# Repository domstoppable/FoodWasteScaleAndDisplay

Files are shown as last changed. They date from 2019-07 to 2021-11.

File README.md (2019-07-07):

# Food waste scale and display

## Firmware
Build and upload with Arduino

## Display app
### Building
* Install [`react-native`](https://facebook.github.io/react-native/docs/getting-started)
* Install the Android SDK
* Make sure the `ANDROID_HOME` environment variable is set appropriately
* Build and test the app
	```bash
	cd ScaleDisplayApp
	npm install
	npm run-android
	```
* Make a native release build and install it ([signing key required](https://facebook.github.io/react-native/docs/signed-apk-android))
	```bash
	cd ScaleDisplayApp/android
	./gradlew assembleRelease
	adb install build/outputs/apk/release/app-release.apk
	cd ..
	```

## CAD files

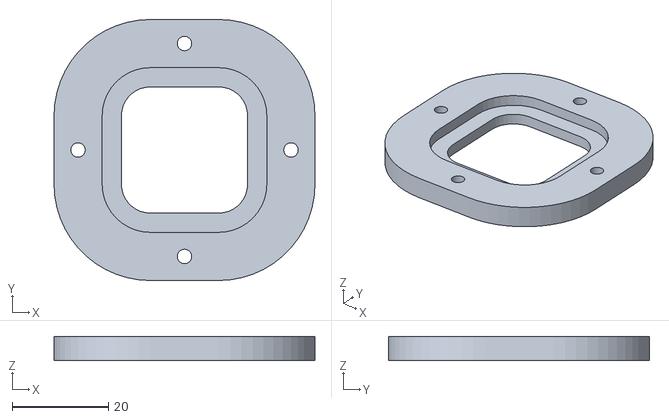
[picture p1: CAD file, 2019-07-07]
3d-models/bracket-plain.stl
54.2 x 54.2 x 5.00

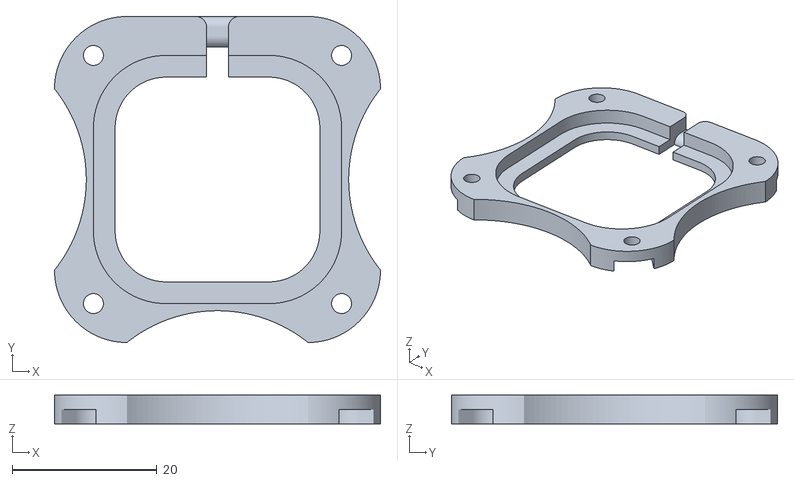
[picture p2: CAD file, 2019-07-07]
3d-models/Load cell bracket.stl
45.0 x 45.0 x 4.00

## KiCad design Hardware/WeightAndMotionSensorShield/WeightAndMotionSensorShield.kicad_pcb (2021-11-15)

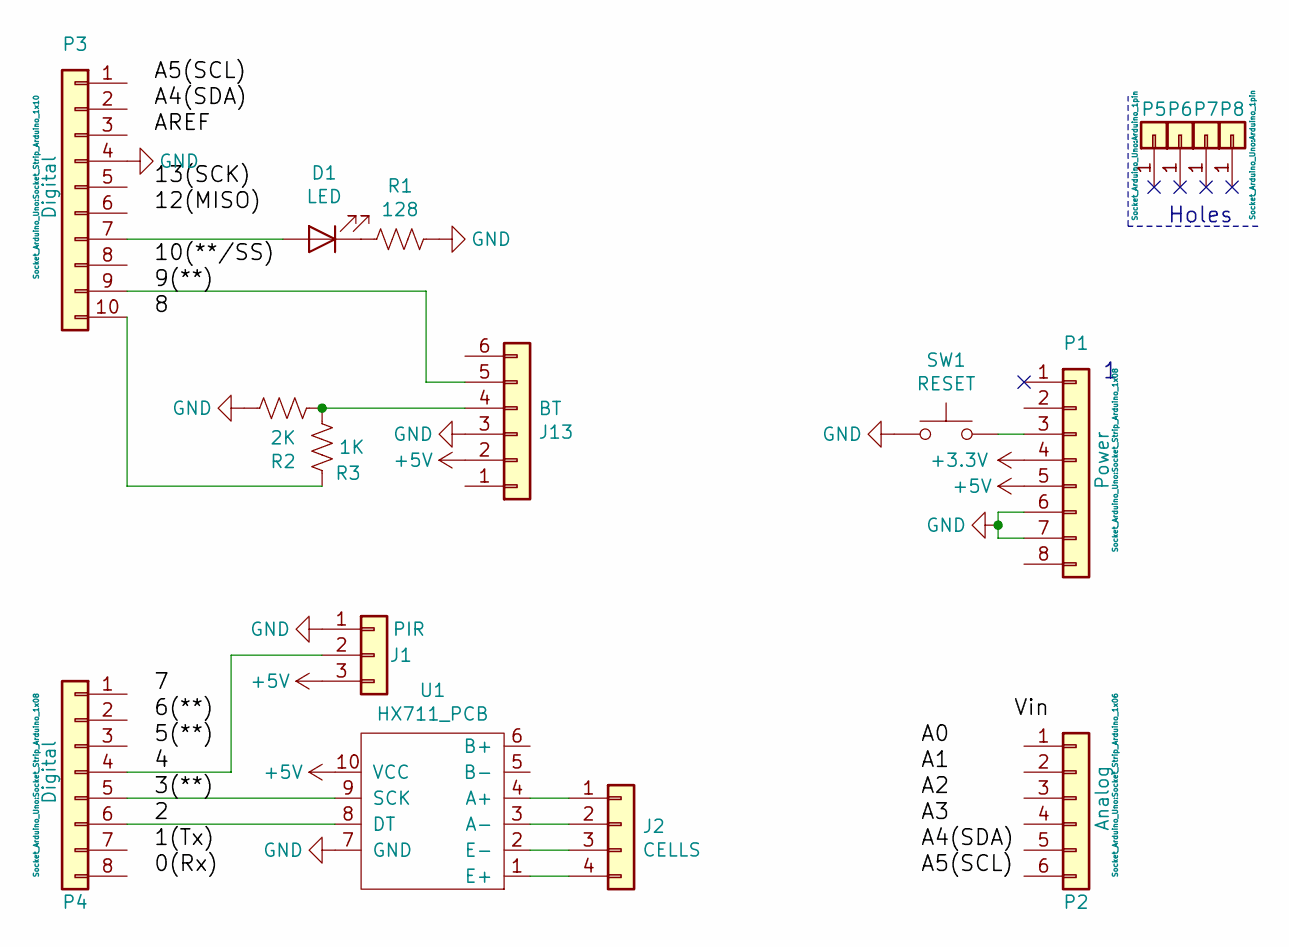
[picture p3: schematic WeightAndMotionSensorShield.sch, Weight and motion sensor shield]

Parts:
D1: LED; LED_D5.0mm
J1: PIR; PinSocket_1x03_P2.54mm_Horizontal
J2: CELLS; PinSocket_1x04_P2.54mm_Horizontal
J13: BT; PinHeader_1x06_P2.54mm_Vertical
P1: Power; Socket_Strip_Arduino_1x08
P2: Analog; Socket_Strip_Arduino_1x06
P3: Digital; Socket_Strip_Arduino_1x10
P4: Digital; Socket_Strip_Arduino_1x08
P5, P6, P7, P8: CONN_01X01; Arduino_1pin
R1: 128; R_Axial_DIN0207_L6.3mm_D2.5mm_P10.16mm_Horizontal
R2: 2K; R_Axial_DIN0207_L6.3mm_D2.5mm_P10.16mm_Horizontal
R3: 1K; R_Axial_DIN0207_L6.3mm_D2.5mm_P10.16mm_Horizontal
SW1: RESET; SW_PUSH_6mm
U1: HX711_PCB

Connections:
+3V3: P1.4
+5V: J1.3, J13.2, P1.5, U1.10 (VCC); also elsewhere on the board
/2: P4.6, U1.8 (DT)
/3(**): P4.5, U1.9 (SCK)
/4: J1.2, P4.4; also elsewhere on the board
/9(**): J13.5, P3.9
GND: J1.1, J13.3, P1.6, P1.7, P3.4, R1.1, R2.1, SW1.1, U1.7 (GND); also elsewhere on the board
unnamed: D1.1 (K), R1.2
unnamed: D1.2 (A), P3.7
unnamed: J2.1, U1.4 (A+)
unnamed: J2.2, U1.3 (A-)
unnamed: J2.3, U1.2 (E-)
unnamed: J2.4, U1.1 (E+)
unnamed: J13.4, R2.2, R3.2
unnamed: P1.3, SW1.2
unnamed: P3.10, R3.1

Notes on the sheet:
Holes

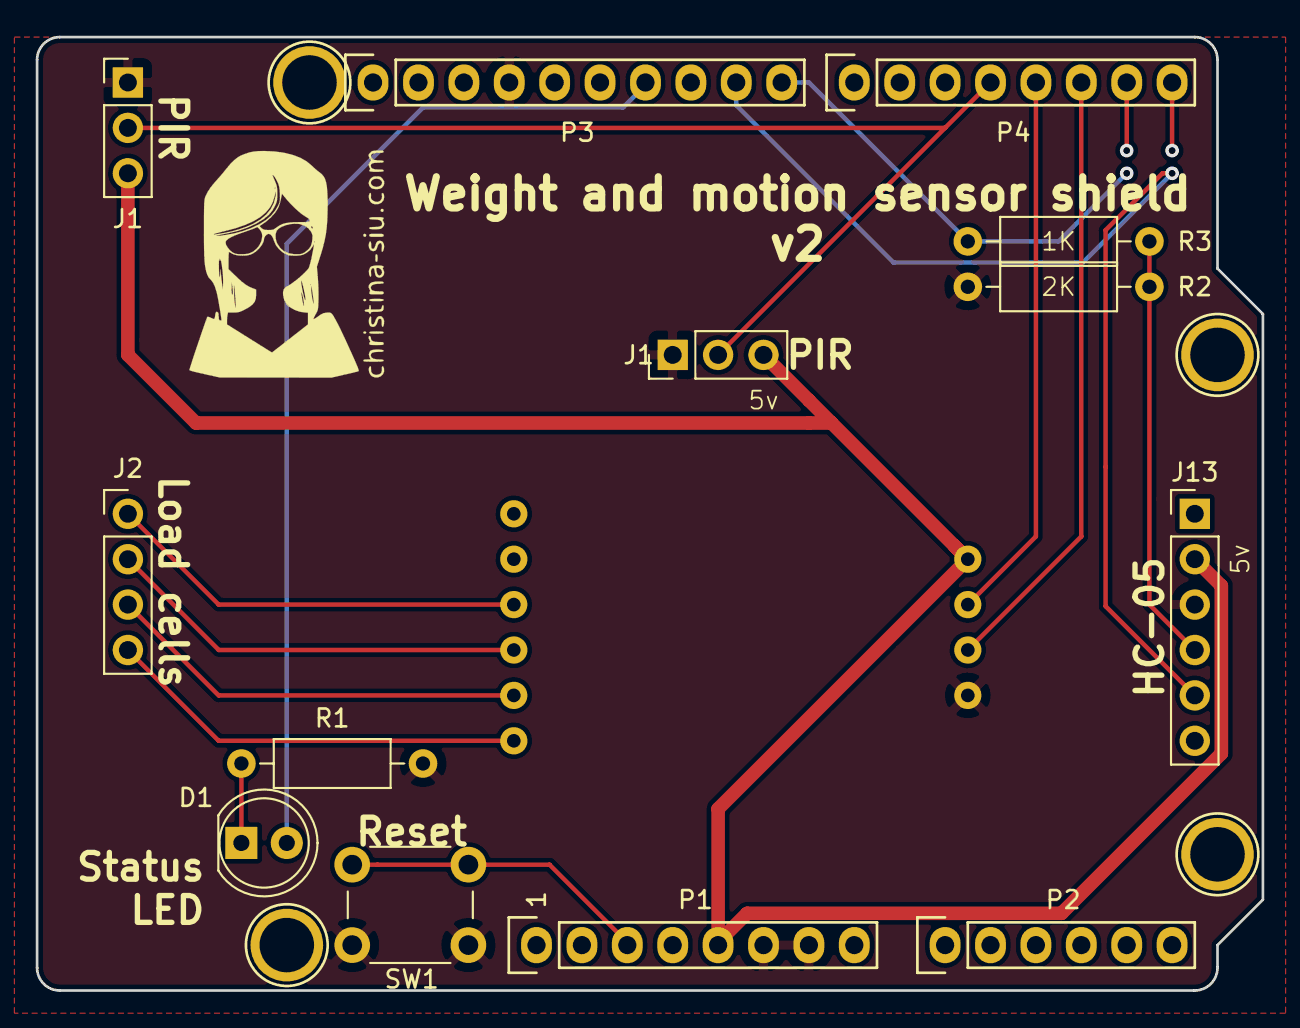
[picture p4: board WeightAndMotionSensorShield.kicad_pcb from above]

Board: 2 copper layers, 68.6 x 53.3 mm, 18 parts (1 on the bottom side), 15 nets.

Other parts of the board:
J1#2: PIR; PinHeader_1x03_P2.54mm_Vertical

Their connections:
+5V: J1#2.3; also elsewhere on the board
/4: J1#2.2; also elsewhere on the board
GND: J1#2.1; also elsewhere on the board

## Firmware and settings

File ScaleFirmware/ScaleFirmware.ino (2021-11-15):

#include <SoftwareSerial.h>
#include "HX711_ADC.h"
#include "PIRSensor.h"

HX711_ADC loadCell(2, 3); // DT, SCK
long lastLoadCellUpdate = 0l;

PIRSensor motionSensor(4);

int ledPin = 11;
long ledOnTime = 0l;
float curWeight = 0;
float calibrationFactor = -5096;
String inputString = "";
SoftwareSerial bluetoothSerial(8, 9); // RX, TX

void setup() {
	Serial.begin(9600);
	Serial.println("Initializing...");
  
	pinMode(ledPin, OUTPUT);

	digitalWrite(ledPin, HIGH);
  	delay(100);
	digitalWrite(ledPin, LOW);

	bluetoothSerial.begin(9600);

	loadCell.begin();
	loadCell.start(2000);
	loadCell.setCalFactor(696.0); // user set calibration factor (float)

	motionSensor.begin();

	for(int i=0; i<3; i++){
		digitalWrite(ledPin, HIGH);
		delay(100);
		digitalWrite(ledPin, LOW);
		delay(100);
	}

	Serial.println("Setup complete! Starting loop...");
}

void loop(){
	long currentTime = millis();

	//if(motionSensor.update()){
	//	if(motionSensor.state && ledOnTime == 0l){
//			bluetoothSerial.println("m");
//      Serial.print("m");
//			Serial.println("Motion detected!");
		///}
		//digitalWrite(ledPin, HIGH);
		//ledOnTime = currentTime;
	//}
	loadCell.update();

	if (currentTime > lastLoadCellUpdate + 500) {
		curWeight = loadCell.getData()*453.592;
    float i =  int(curWeight); //grams //float(int(curWeight/10))/100; //kg
		float v = loadCell.getCalFactor();

		bluetoothSerial.print("w");
		bluetoothSerial.println(i);
   Serial.print("Calibration Factor: ");
   Serial.print(calibrationFactor);
   Serial.print("Sending weight: ");
   Serial.println(i);
//		Serial.print("Sending weight: ");
//		Serial.println(i);

		lastLoadCellUpdate = currentTime;
	}
        
//	if(ledOnTime > 0l && currentTime > ledOnTime + 1000){
//		ledOnTime = 0l;
//		Serial.println("Disabling LED");
//		digitalWrite(ledPin, LOW);
//	}
 if(bluetoothSerial.available()>0)
  {
//    bluetoothSerial.println("P");
    char temp = bluetoothSerial.read();
    Serial.println(temp);
    if(temp == 't'){
      loadCell.tare(); //Reset the scale to 0
      bluetoothSerial.println("R");
    }
    else if(temp == 'a'){
      calibrationFactor += 500;
      loadCell.setCalFactor(calibrationFactor);
      bluetoothSerial.println("A");
    }
    else if(temp == 'z'){
      calibrationFactor -= 500;
      loadCell.setCalFactor(calibrationFactor);
      bluetoothSerial.println("Z");
    }
    else if(temp == 's'){
      calibrationFactor += 50;
      loadCell.setCalFactor(calibrationFactor);
      bluetoothSerial.println("A");
    }
    else if(temp == 'x'){
      calibrationFactor -= 50;
      loadCell.setCalFactor(calibrationFactor);
      bluetoothSerial.println("Z");
    }
    else if(temp=='g'){
      bluetoothSerial.print('g');
      bluetoothSerial.println(calibrationFactor);
      
    }
    else if(temp=='h'){
      delay(1000);
      float temp2 = bluetoothSerial.parseInt();
      
//      while(bluetoothSerial.available()>0){
//        delay(100);
//        char inChar = bluetoothSerial.read();
//        Serial.println(inChar);
//        inputString += inChar; 
//      }
////      float temp3 = bluetoothSerial.parseInt();
//      Serial.println(inputString);
//      inputString = "";
      calibrationFactor = float(temp2);
//      bluetoothSerial.println(temp2);
      Serial.println(calibrationFactor);
      loadCell.setCalFactor(calibrationFactor);
    }
      
      
      
  }
}

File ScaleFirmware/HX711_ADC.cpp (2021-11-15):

//-------------------------------------------------------------------------------------
// HX711_ADC.h
// Arduino master library for HX711 24-Bit Analog-to-Digital Converter for Weigh Scales
// Olav Kallhovd sept2017
// Tested with      : HX711 asian module on channel A and YZC-133 3kg load cell
// Tested with MCU	: Arduino Nano
//-------------------------------------------------------------------------------------

#include <Arduino.h>
#include "HX711_ADC.h"


HX711_ADC::HX711_ADC(uint8_t dout, uint8_t sck) //constructor
{ 	
	doutPin = dout;
	sckPin = sck;
} 

void HX711_ADC::setGain(uint8_t gain)  //value should be 32, 64 or 128*
{
	if(gain < 64) GAIN = 2; //32, channel B
	else if(gain < 128) GAIN = 3; //64, channel A
	else GAIN = 1; //128, channel A
}

void HX711_ADC::begin()
{
	pinMode(sckPin, OUTPUT);
	pinMode(doutPin, INPUT);
	setGain(128);
	powerUp();
}


void HX711_ADC::begin(uint8_t gain)
{
	pinMode(sckPin, OUTPUT);
	pinMode(doutPin, INPUT);
	setGain(gain);
	powerUp();
}

/*  start(t): will do conversions continuously for 't' +400 milliseconds (400ms is min. settling time at 10SPS). 
*   Running this for 1-5s before tare() seems to improve the tare accuracy */
int HX711_ADC::start(unsigned int t)
{
	t += 400;
	while(millis() < t) 
	{
		getData();
		yield();
	}
	tare();
	tareStatus = 0;
}	

/*  startMultiple(t): use this if you have more than one load cell and you want to do tare and stabilization simultaneously.
	Will do conversions continuously for 't' +400 milliseconds (400ms is min. settling time at 10SPS). 
*   Running this for 1-5s before tare() seems to improve the tare accuracy */
int HX711_ADC::startMultiple(unsigned int t)
{
	tareTimeoutFlag = 0;
	static unsigned long timeout = millis() + tareTimeOut;
	if(startStatus == 0) {
		if(isFirst) {
			startMultipleTimeStamp = millis();
			if (t < 400) 
			{
				startMultipleWaitTime = t + 400; //min time for HX711 to be stable
			} 
			else 
			{
				startMultipleWaitTime = t;
			}
			isFirst = 0;
		}	
		if(millis() < startMultipleTimeStamp + startMultipleWaitTime) {
			update(); //do conversions during stabilization time
			yield();
			return 0;
		}
		else { //do tare after stabilization time is up
			doTare = 1;
			update();
			if(convRslt == 2) 
			{	
				doTare = 0;
				convRslt = 0;
				startStatus = 1;
			}
			if (!tareTimeoutDisable) 
			{
				if (millis() > timeout) 
				{ 
				tareTimeoutFlag = 1;
				return 1; // Prevent endless loop if no HX711 is connected
				}
			}
		}
	}
	return startStatus;
}

void HX711_ADC::tare() 
{
	uint8_t rdy = 0;
	doTare = 1;
	tareTimes = 0;
	tareTimeoutFlag = 0;
	unsigned long timeout = millis() + tareTimeOut;
	while(rdy != 2) 
	{
		rdy = update();
		if (!tareTimeoutDisable) 
		{
			if (millis() > timeout) 
			{ 
				tareTimeoutFlag = 1;
				break; // Prevent endless loop if no HX711 is connected
			}
		}
		yield();
	}
}

bool HX711_ADC::getTareStatus() 
{
	bool t = tareStatus;
	tareStatus = 0;
	return t;
}

void HX711_ADC::tareNoDelay() 
{
	doTare = 1;
	tareTimes = 0;
}

void HX711_ADC::setCalFactor(float cal) //raw data is divided by this value to convert to readable data
{
	calFactor = cal;
}

float HX711_ADC::getCalFactor() //raw data is divided by this value to convert to readable data
{
	return calFactor;
}

//call function update() in loop
//if conversion is ready; read out 24 bit data and add to data set, returns 1
//if tare operation is complete, returns 2
//else returns 0
uint8_t HX711_ADC::update() 
{
	byte dout = digitalRead(doutPin); //check if conversion is ready
	if (!dout) 
	{
		conversion24bit();
		//if(s) Serial.print(s);
	}
	else convRslt = 0;
	return convRslt;
}

float HX711_ADC::getData() // return fresh data from the moving average data set
{
	//long k = 0;
	long data = 0;
	//data = smoothedData() - tareOffset;
	lastSmoothedData = smoothedData();
	data = (lastSmoothedData >> divBit) - tareOffset ;
	//data = (data >> divBit);
	
	float x = (float)data / calFactor;
	return x;
}

long HX711_ADC::smoothedData() 
{
	long data = 0;
	long L = 0xFFFFFF;
	long H = 0x00;
	//for (uint8_t r = 0; r < DATA_SET; r++) {
	for (uint8_t r = 0; r < (samplesInUse + IGN_HIGH_SAMPLE + IGN_LOW_SAMPLE); r++) 
	{
		if (L > dataSampleSet[r]) L = dataSampleSet[r]; // find lowest value
		if (H < dataSampleSet[r]) H = dataSampleSet[r]; // find highest value
		data += dataSampleSet[r];
	}
	if(IGN_LOW_SAMPLE) data -= L; //remove lowest value
	if(IGN_HIGH_SAMPLE) data -= H; //remove highest value
	return data;
}

uint8_t HX711_ADC::conversion24bit()  //read 24 bit data and start the next conversion
{
	conversionTime = micros() - conversionStartTime;
	conversionStartTime = micros();
	unsigned long data = 0;
	uint8_t dout;
	convRslt = 0;
	if(SCK_DISABLE_INTERRUPTS) noInterrupts();
	for (uint8_t i = 0; i < (24 + GAIN); i++) 
	{ //read 24 bit data + set gain and start next conversion
		if(SCK_DELAY) delayMicroseconds(1); // could be required for faster mcu's, set value in config.h
		digitalWrite(sckPin, 1);
		if(SCK_DELAY) delayMicroseconds(1); // could be required for faster mcu's, set value in config.h
		if (i < (24)) 
		{
			dout = digitalRead(doutPin);
			data = data << 1;
			if (dout) 
			{
				data++;
			}
		}
		digitalWrite(sckPin, 0);
	}
	if(SCK_DISABLE_INTERRUPTS) interrupts(); 
	data = data ^ 0x800000; // if out of range (min), change to 0
	//if (readIndex == DATA_SET - 1) {
	if (readIndex == samplesInUse + IGN_HIGH_SAMPLE + IGN_LOW_SAMPLE - 1) 
	{
		readIndex = 0;
	}
	else 
	{
		readIndex++;
	}
	if(data > 0)  
	{
		convRslt++;
		dataSampleSet[readIndex] = (long)data;
		if(doTare) 
		{
			if (tareTimes < DATA_SET) 
			{
				tareTimes++;
			}
			else 
			{
				//tareOffset = smoothedData();
				tareOffset = (smoothedData() >> divBit);
				tareTimes = 0;
				doTare = 0;
				tareStatus = 1;
				convRslt++;
			}
		}
	}
}

void HX711_ADC::powerDown() 
{
	digitalWrite(sckPin, LOW);
	digitalWrite(sckPin, HIGH);
}

void HX711_ADC::powerUp() 
{
	digitalWrite(sckPin, LOW);
}

//get the tare offset (raw data value output without the scale "CalFactor")
long HX711_ADC::getTareOffset() 
{
	return tareOffset;
}

//set new tare offset (raw data value input without the scale "CalFactor")
void HX711_ADC::setTareOffset(long newoffset)
{
	tareOffset = newoffset;
}

//for testing and debugging:
//returns current value of readIndex
int HX711_ADC::getReadIndex()
{
	return readIndex;
}

//for testing and debugging:
//returns latest conversion time in millis
float HX711_ADC::getConversionTime()
{
	return conversionTime/1000.0;
}

//for testing and debugging:
//returns the HX711 samples ea seconds based on the latest conversion time. 
//The HX711 can be set to 10SPS or 80SPS. For general use the recommended setting is 10SPS.
float HX711_ADC::getSPS()
{
	float sps = 1000000.0/conversionTime;
	return sps;
}

//for testing and debugging:
//returns the tare timeout flag from the last tare operation. 
//0 = no timeout, 1 = timeout
bool HX711_ADC::getTareTimeoutFlag() 
{
	return tareTimeoutFlag;
}
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

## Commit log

2019-07-16 Add PCB design for Arduino shield
    [WeightAndMotionSensorShield-B.Cu.gbl, WeightAndMotionSensorShield-B.Mask.gbs, WeightAndMotionSensorShield-B.SilkS.gbo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]
2019-07-23 Adds LED, reset button, 2nd PIR header
    [WeightAndMotionSensorShield-B.Cu.gbl, WeightAndMotionSensorShield-B.Mask.gbs, WeightAndMotionSensorShield-B.SilkS.gbo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]
2019-08-18 PCB v1.1 and 2 changes
    [WeightAndMotionSensorShield-B.Cu.gbl, WeightAndMotionSensorShield-B.Mask.gbs, WeightAndMotionSensorShield-B.SilkS.gbo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]
2019-10-10 Added functioning Baseline and Ambient conditions. Need pictures and colors for the Ambient and Metaphorical conditions. Data can be logged locally via RNFetchBlob Operator button located in the bott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
    TODO: Google Sheets and Weight detector (to determine logging)
2020-01-10 More functions
    [config.txt]
2020-01-12 Sort of functioning for BLE devices, but the HC-05 unit ordered is not BLE
2020-01-12 Working bluetooth data reader. Need to do a lot more to stabilize things
    1) Bluetooth picker
    2) Auto-connect
    3) Properly disconnect bluetooth device so you do not need to completely disconnect bluetooth from power
2020-01-13 Added arduino updated script so that we can send command to tare
2020-01-13 Added calibration menu Added ToastAndroid instead of console.warns everywhere for some crisper tastes Need to figure out weightchange algorithm. Can detect changes, but need to think of how to contin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
    [config.txt]
2020-01-20 Add header for HC-05 module
    [WeightAndMotionSensorShield.kicad_pcb, WeightAndMotionSensorShield.sch]
2020-03-07 Fixed calibrations to save values from configCal file
2020-03-14 Update pins for new board + add LED pin
2020-04-19 Updated ScaleFirmware for calibrations
2021-04-15 Cleaned up buttons

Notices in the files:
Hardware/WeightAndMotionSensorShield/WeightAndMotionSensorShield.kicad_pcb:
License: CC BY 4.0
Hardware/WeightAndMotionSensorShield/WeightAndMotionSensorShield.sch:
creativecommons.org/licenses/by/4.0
